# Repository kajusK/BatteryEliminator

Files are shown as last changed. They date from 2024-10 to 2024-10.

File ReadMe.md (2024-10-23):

# Battery eliminator for NavComm NC-55A

The aim of this project is to eliminate battery from the [NavComm NC-55A airband](https://navcomm.eu/en/air-band/15-handheld-air-band-radio-with-vor-and-bluetooth-5907662381407.html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)
radio by providing a regulated voltage supply directly through the battery
contacts of the radio.

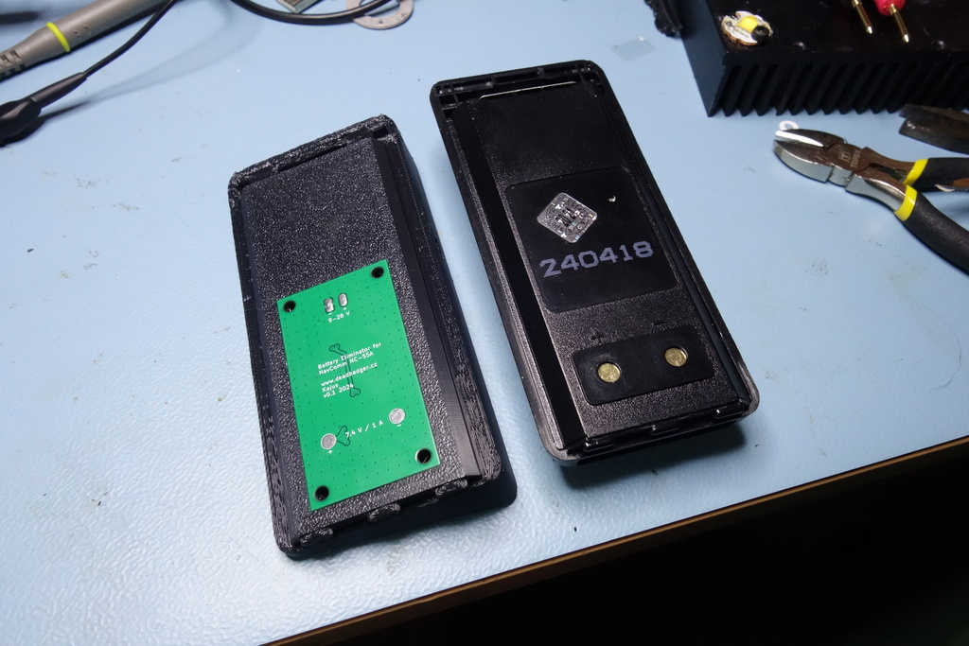
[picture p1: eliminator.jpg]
eliminator


## Design constraints

- Radio uses 2 cell Li-Ion battery used -> 7.4 V nominal working voltage
- Radio current consumption: 1 A for Tx, 70 mA for Rx per manual
- Input voltage range 8-28 V of aircraft power bus (12 V nominal)
- Good input voltage noise filtering is needed - spikes on engine startup, etc.

## Mechanical design

- The mechanical part (holder) of the project was designed in a way that it can be clicked to the radio back in similar way as the battery
- The holder serves as a battery replacement and in the same time as a mounting point of the radio to the aircraft panel
- A simple connector to accomodate 2 jacks needed by the radio (mic, headphones, PTT) is included in the design files
- Design files can be found in [3d folder](./3d) or on my [Onshape profile](https://cad.onshape.com/documents/5d88d10385b6e47e38e9babd/w/7460efe50eb1ed31b91b954c/e/4510368ee41f3908bf5426d3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)

## PCB Design

### Input protection

- Polarity protection using **SBR3U40S1F** diode
- Transient protections using **SMDJ28CA** 28V 3kW TVS diode
- Shorts protection using a fuse - assuming 1 A output and 80 % efficiency at minimum working voltage, 1.3 A hold current at 80°C is needed. The **C1Q 1.25** will be used.

### Input filtering

A simple SMD ferrite bead followed by 100 nF and Buck converter input capacitors
provides input filtering to reduce amount of noise going from the DC/DC supply
to the aircraft power bus.

### DC-DC converter

As the voltage difference is quite high (worst case 28 - 7.4 = 20.6 V / 1 A
output), the LDO is not a good choice here, switching supply is needed.

- Buck topology
- ~8-30+ V input voltage range
- more than 1 A output current
- Large output current range (light load mode is possible)

The **AP63200WU-7** was selected as it matches all requirements and
requires a minimum amount of external parts.

- 2 A output current limit
- 3.8 - 32 V input voltage
- 500 kHz switching frequency with spread spectrum to reduce EMI
- integrated MOSFETs
- PFM mode for high efficiency on low output currents
- Overvoltage and overtemperature protection

The feedback voltage reference is 0.8 V, a 75k and 9k1 5% resistors will be used,
giving output voltage (worst case) between 6.77 and 8.09 V which is well within
input voltage range of the radio, a 1 % resistors would be better though.

The inductor will be (assuming 50 % ripple current of 2 A - 1 A):

$$ L = \frac{V_{out}(V_{in}-V_{out})}{V_{in}\Delta I_L f_{sw}} = \frac{7.4 (28-7.4)}{28*1*500000} = 10.9 \mu H $$

The datasheet recommended maximum inductance od 10 $$\mu H$$, so let's stick with
this. The recommended RDC is 100 $m\Omega$ and saturation current 35 % higher than peak one.
The **SRR6028-100Y** was selected.

### Output filtering

Output is fed through a ferrite bead to a parallel combination of small ceramic
capacitor and a large capacitor with higher ESR to provide some dumping.

### Output protection

The output of the switching regulator is separated from radio by a fuse
and a TVS diode to protect the circuit from ESD when radio is not connected.

## Testing

- Measured at 13 V input voltage (usual value when engine is running in 12 V based aircraft power system)
- Radio consumption pulses between 20 and 44 mA in Rx while battery saving is enabled, the coil makes annoying buzzing noise
- With battery saving off -> 44 mA constant current, the coil makes very weak high pitch sound
- With backlight on, consumption is 90 mA, no audible noise from coil
- When transmitting, the consumption is around 700 mA

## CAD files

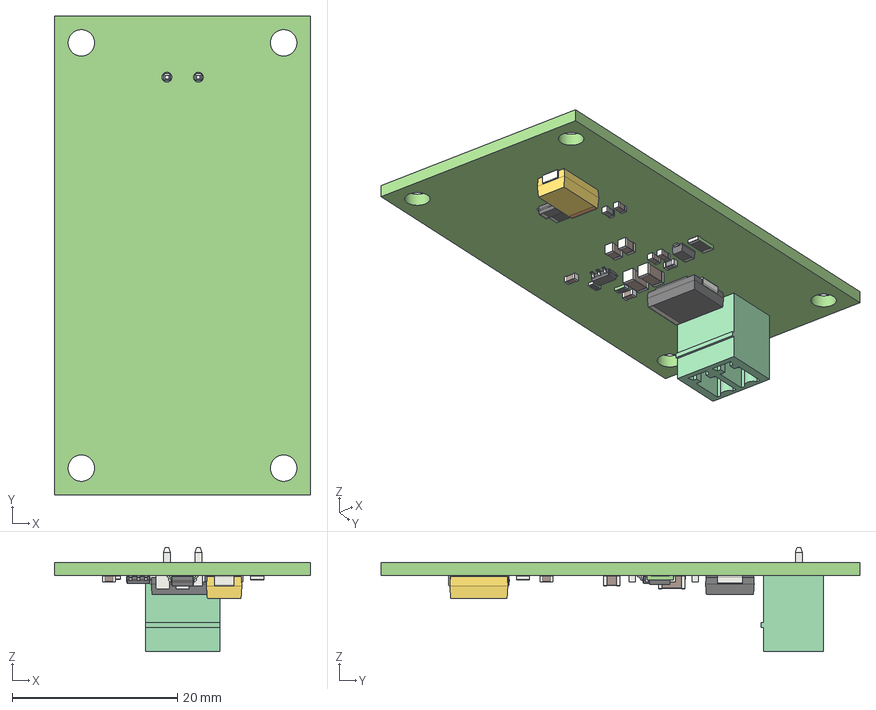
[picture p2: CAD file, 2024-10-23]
3d/PCB.step
31.0 x 58.0 x 12.6 mm

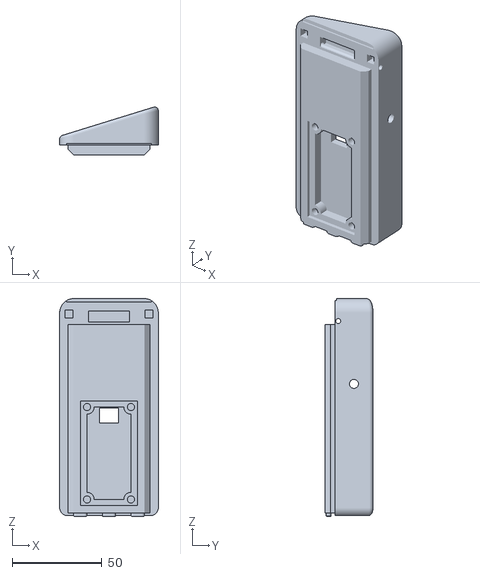
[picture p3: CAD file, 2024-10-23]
3d/holder.stl
55.0 x 26.8 x 121.5

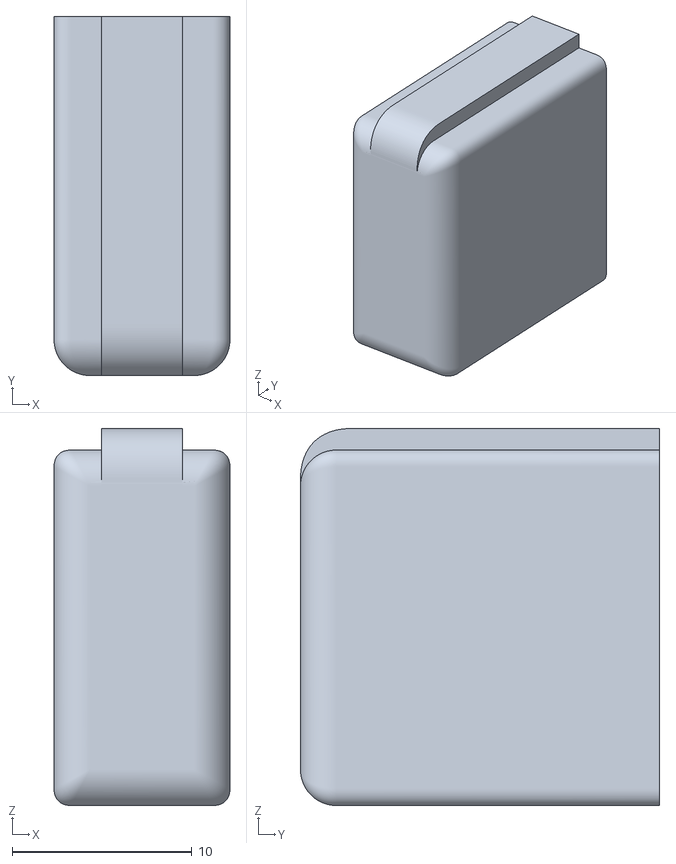
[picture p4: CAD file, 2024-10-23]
3d/connector.stl
9.80 x 20.0 x 21.0

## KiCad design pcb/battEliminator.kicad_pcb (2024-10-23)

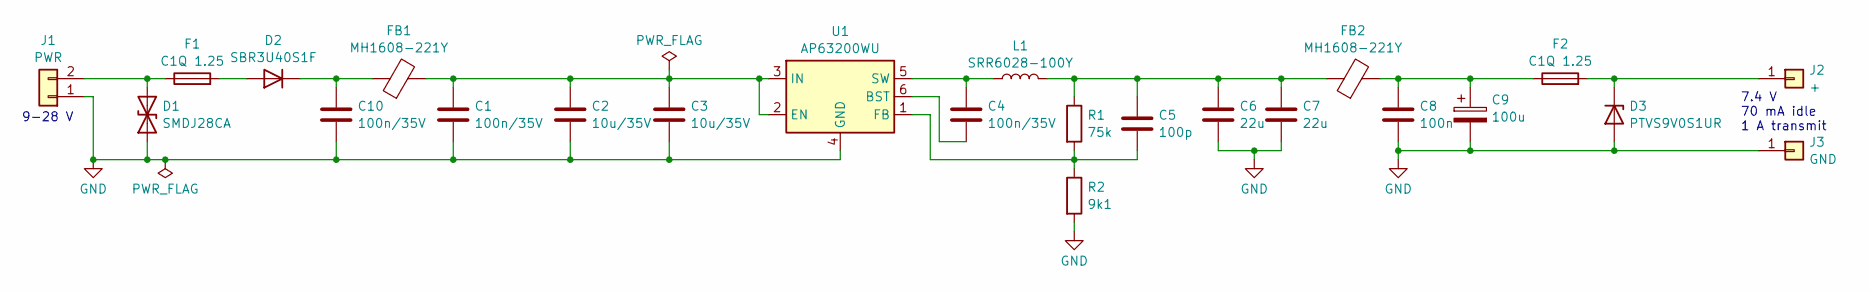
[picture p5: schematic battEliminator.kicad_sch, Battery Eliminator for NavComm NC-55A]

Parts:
C1, C4, C10: 100n/35V; C_0603_1608Metric
C2, C3: 10u/35V; C_1206_3216Metric; Mouser number 187-CL31B106KBHNNNE
C5: 100p; C_0603_1608Metric; Mouser number 80-C0603C101J1G
C6, C7: 22u; C_0805_2012Metric; Mouser number 81-GRM21BR61E226ME4L
C8: 100n; C_0603_1608Metric
C9: 100u; CP_EIA-7343-30_AVX-N; Mouser number 581-TAJD107M016R
D1: SMDJ28CA; D_SMC; Mouser number 576-SMDJ28CA
D2: SBR3U40S1F; D_SOD-123F; Mouser number 621-SBR3U40S1F-7
D3: PTVS9V0S1UR; D_SOD-123
F1, F2: C1Q 1.25; Fuse_1206_3216Metric; Mouser number 530-C1Q1.25
FB1, FB2: MH1608-221Y; L_0603_1608Metric; Mouser number 652-MH1608-221Y
J1: PWR; PhoenixContact_MCV_1,5_2-G-3.81_1x02_P3.81mm_Vertical
J2: +; TestPoint_Pad_D3.0mm
J3: GND; TestPoint_Pad_D3.0mm
L1: SRR6028-100Y; L_Cenker_CKCS8040; Mouser number 652-SRR6028-100Y
R1: 75k; R_0603_1608Metric
R2: 9k1; R_0603_1608Metric
U1: AP63200WU; TSOT-23-6; Mouser number 621-AP63200WU-7

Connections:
GND: C1.2, C2.2, C3.2, C6.2, C7.2, C8.2, C9.2, C10.2, D1.1 (A1), D3.2 (A), J1.1, J3.1, R2.2, U1.4 (GND)
unnamed: C5.1, C6.1, C7.1, FB2.1, L1.2, R1.1
unnamed: C8.1, C9.1, F2.1, FB2.2
unnamed: D1.2 (A2), F1.1, J1.2
unnamed: D2.2 (A), F1.2
unnamed: C10.1, D2.1 (K), FB1.1
unnamed: D3.1 (K), F2.2, J2.1
unnamed: C4.1, U1.6 (BST)
unnamed: C1.1, C2.1, C3.1, FB1.2, U1.2 (EN), U1.3 (IN)
unnamed: C5.2, R1.2, R2.1, U1.1 (FB)
unnamed: C4.2, L1.1, U1.5 (SW)

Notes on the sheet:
9-28 V
7.4 V 70 mA idle 1 A transmit

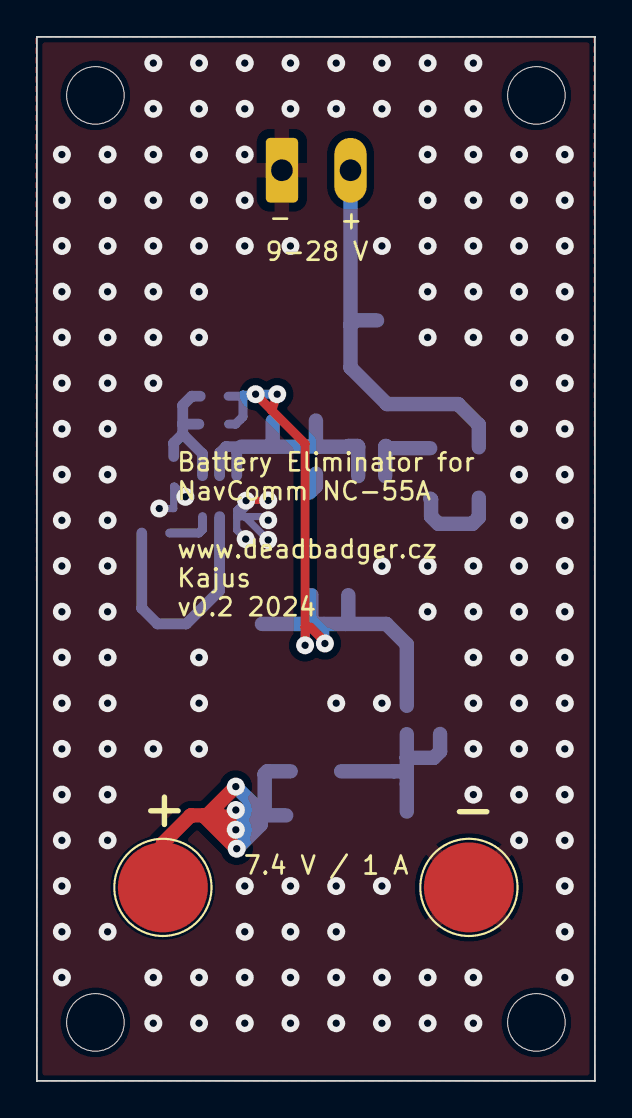
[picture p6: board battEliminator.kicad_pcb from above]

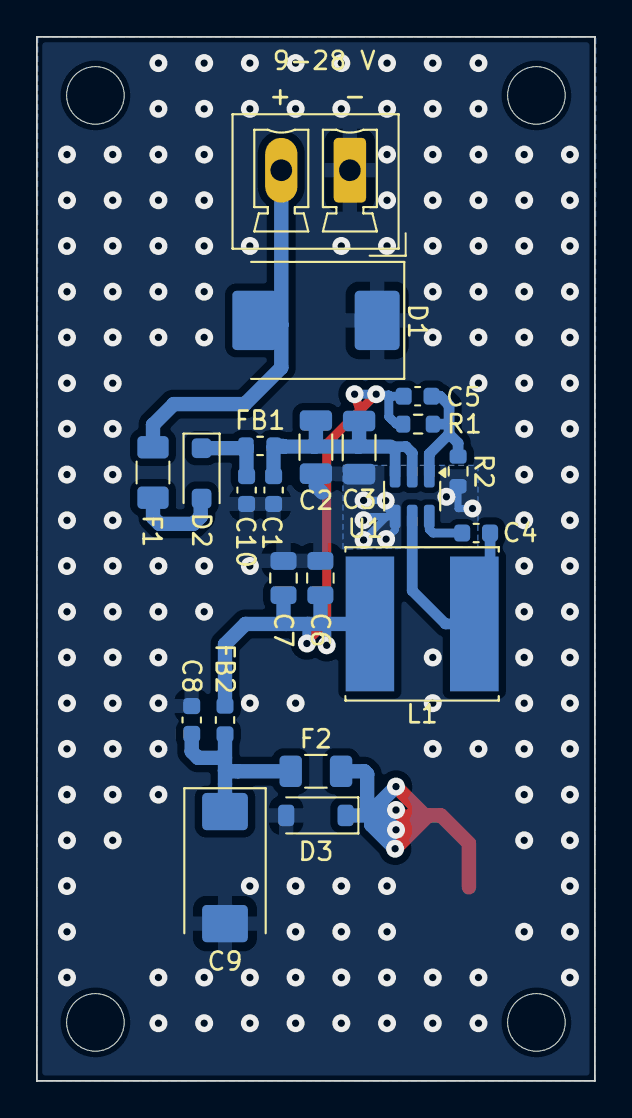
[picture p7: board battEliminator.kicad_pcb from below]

Board: 2 copper layers, 31.0 x 58.0 mm, 24 parts (22 on the bottom side), 11 nets.

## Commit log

2024-08-26 Added readme and PCB design
    [battEliminator.kicad_pcb, battEliminator.kicad_sch]
2024-08-26 Added gerber files for PCB
    [battEliminator-B_Cu.gbl, battEliminator-B_Mask.gbs, battEliminator-B_Paste.gbp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]
2024-10-23 Fixed size and position of the radio battery pads
    [battEliminator.kicad_pcb]
2024-10-23 Regenerated gerbers for pcb v0.2
    [battEliminator-B_Cu.gbl, battEliminator-B_Mask.gbs, battEliminator-B_Paste.gbp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]
2024-10-23 Added remaining design files and image
    [PCB.step, connector.stl, holder.stl]
